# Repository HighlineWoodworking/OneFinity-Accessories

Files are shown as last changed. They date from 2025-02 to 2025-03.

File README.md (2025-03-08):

# OneFinity-Accessories
Accessories for a [OneFinity CNC Machine](https://www.onefinitycnc.com/).

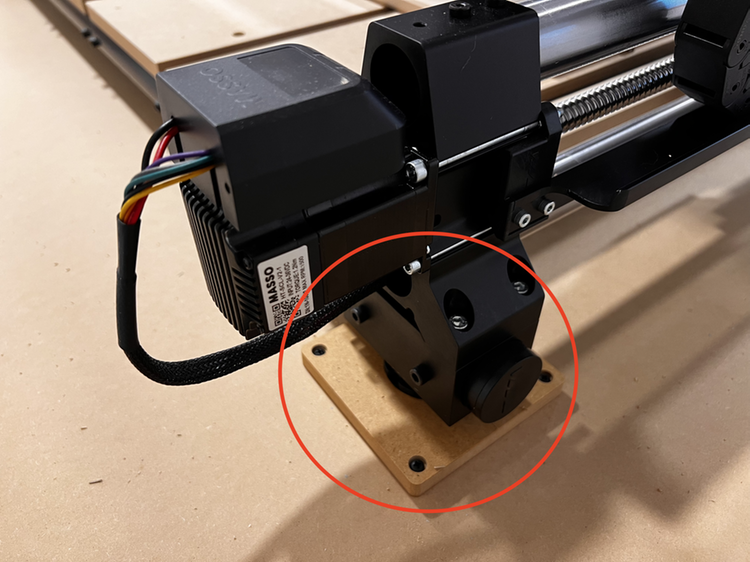
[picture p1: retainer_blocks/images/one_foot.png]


[Retainer Blocks](retainer_blocks/README.md)

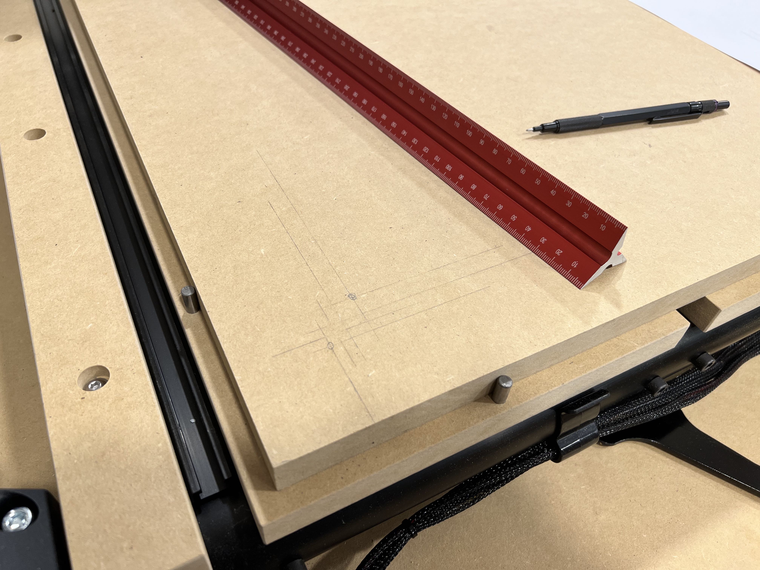
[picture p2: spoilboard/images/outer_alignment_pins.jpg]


[Spoilboard (work in progress)](spoilboard/README.md)

## Using

Projects and files are 100% free to use under [CC0](https://creativecommons.org/public-domain/cc0/).

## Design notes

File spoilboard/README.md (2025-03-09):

# Spoilboard

Spoilboard setup on a [OneFinity Journeyman Elite](https://www.onefinitycnc.com/product-page/elite-series-journeyman-48-x32-cut-area) with a QCW frame.  

Utilizes one or more sacrifical layers on top of the QCW slats.

## Advantages

* Multiple levels provide felxibility, minimize torque, and protect the QCW slats
* Alignment pins maintain a high-degree of repeatable accuracy
* Embedded hurricane nuts allow for secure, low-profile hold-downs
* Follows the "MFT Standard" 96mm grid spacing

## Disadvantages

* Not ideal where a maximum z-range is needed
* "MFT Standard" adds complexity, a simpler grid system would be better

## Steps

1. Flatten QCW boards
2. Machine [Outer Alignment Holes](outer_alignment_holes.md)
3. Setup lower spoilboard blank
4. [Add Fastening Holes](fastening_holes.md)

## Materials

* [1/4" Alignment Pins McMaster-Carr](https://www.mcmaster.com/catalog/131/3826/98381A542)

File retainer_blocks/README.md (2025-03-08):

# OneFinity QCW Retainer Blocks

Retainer blocks to secure the OneFinity Elite QCW to a table. The frame combined with the OneFinity is rock solid, but the blocks provide extra protection to keep the machine from "walking" across the table. Blocks are split in half allowing them to be installed once the machine is setup.

QCW Retainer Block on one Foot.

## Notes

* drawing units are mm
* 300 x 340mm blank
* 12.7mm (1/2 inch) MDF
* simple machining with 1/4 inch end mill
* (16) x #8 1 inch coarse pan head screws to secure blocks to a work surface
* [Amazon Link for Screws](https://www.amazon.com/gp/product/B01M63E8DR/ref=ppx_yo_dt_b_search_asin_title?ie=UTF8&psc=1)
* inset fastening holes 3mm

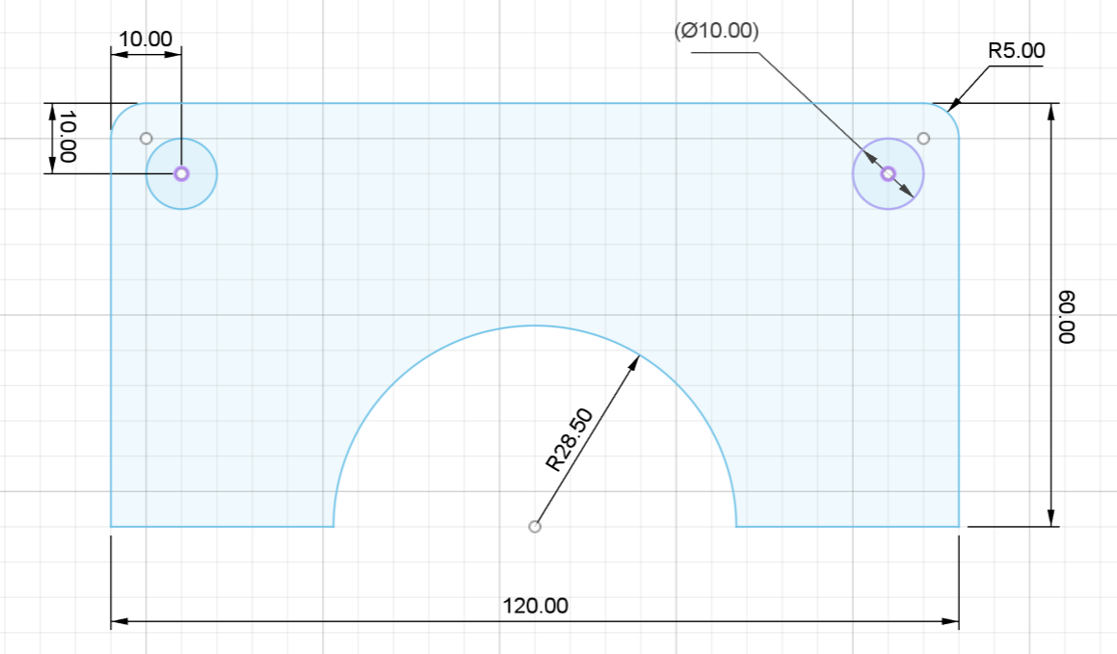
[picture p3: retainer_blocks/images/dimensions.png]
QCW Retainer Block dimensions.


## Files

* qcw_retainer_blocks_v01.art = [Carveco Maker](https://carveco.com/carveco-software-range/carveco-maker/) source file
* qcw_retainer_blocks_v01.dxf = [DXF](https://en.wikipedia.org/wiki/AutoCAD_DXF) source file 

## Versions

* v01 | 9-Feb-2025 | inital post

Finished pieces can also be purchased from the [Highline Woodworking Etsy Shop](https://www.etsy.com/shop/HighlineWoodworking)

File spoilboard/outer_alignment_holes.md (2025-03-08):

# Outer Alignment Holes

* Precisely aligns left and bottom edge of spoilboard on the QCW frame
* Peck holes 12.7mm deep (1/2 inch) using a 1/4 inch up-cut end mill, for example:
  * [Woodpeckers US2100U](https://www.woodpeck.com/ultra-shear-2-flute-quarter-inch-solid-carbide-spiral-bits.html)
* Holes are setup so board is positioned 10mm in from lower-left edge of left-most large QCW slat
* For 1/4 inch bit, hole center is 6.825mm from edges
* Holes spaced approximately in the middle of the QCW boards along X and equally along Y
* Alignment pins are more accurate and reliable than using a line and manually positioning the spoilboard
* Since the holes are CNC routed the spoilboard will be precisely aligned with the CNC X and Y axes

Outer alignment pins.
Spoilboard aligned with 1/4 inch alignment pins 10mm in from the lower-left corner of the leftmost wide QCW slat.

## Files

* outer_alignment_holes.art = [Carveco Maker](https://carveco.com/carveco-software-range/carveco-maker/) source file
* outer_alignment_holes.dxf = [DXF](https://en.wikipedia.org/wiki/AutoCAD_DXF) exported source file
* outer_alignment_holes.dwg = AutoCad drawing file created with [Siemens Solid Edge 2D](https://resources.sw.siemens.com/en-US/download-free-2d-cad-software/)

## Dimensions

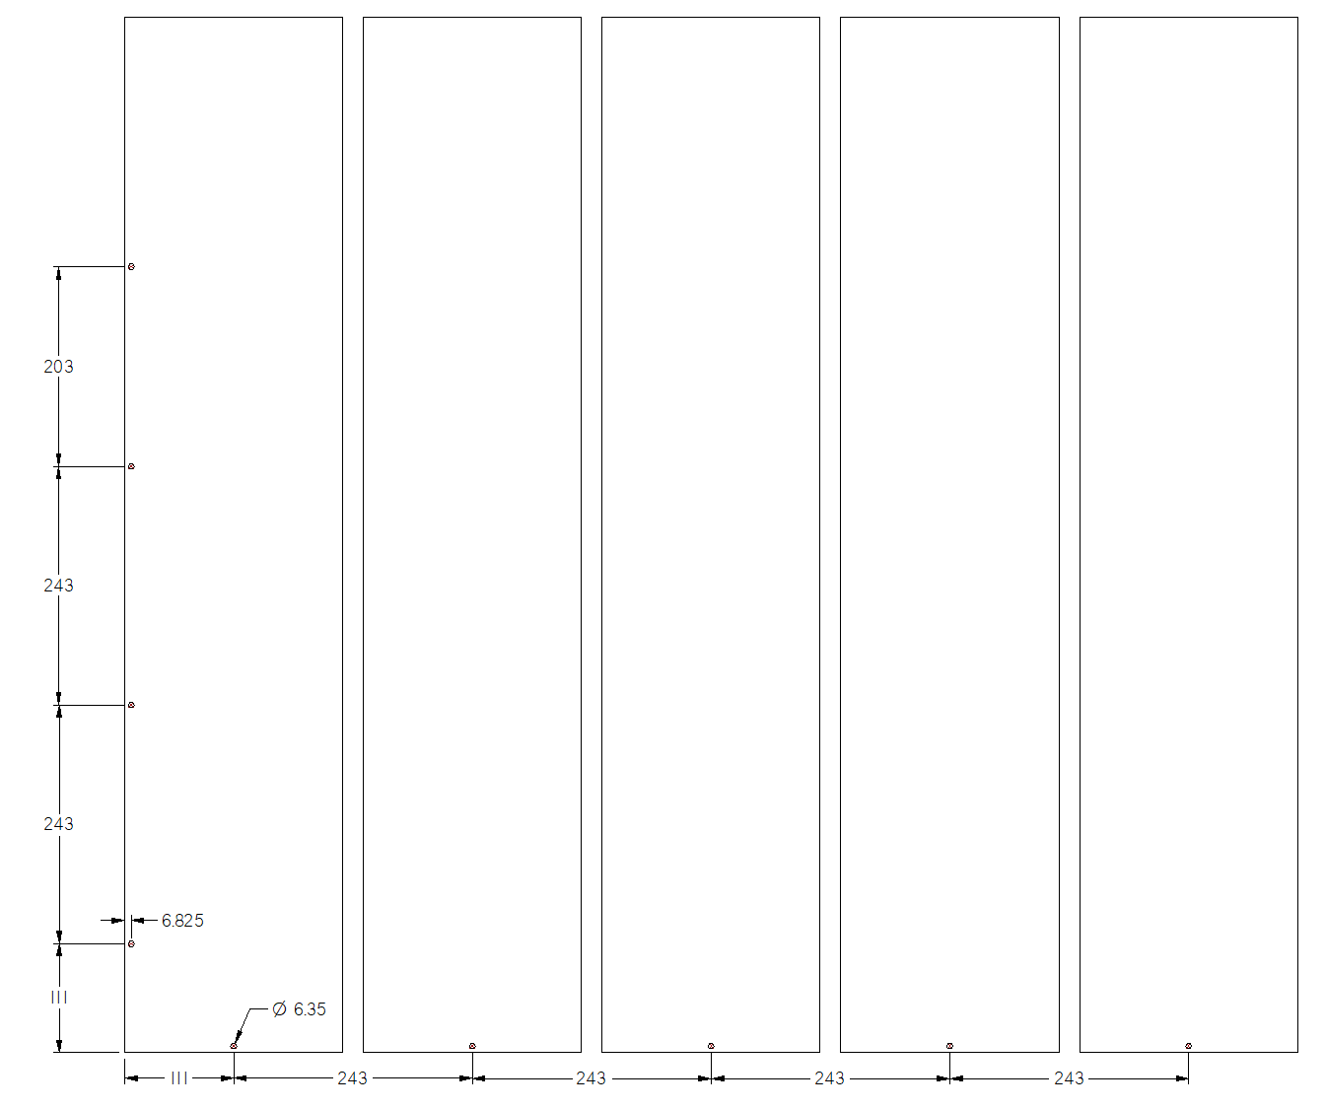
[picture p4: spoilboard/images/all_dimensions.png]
All dimensions.


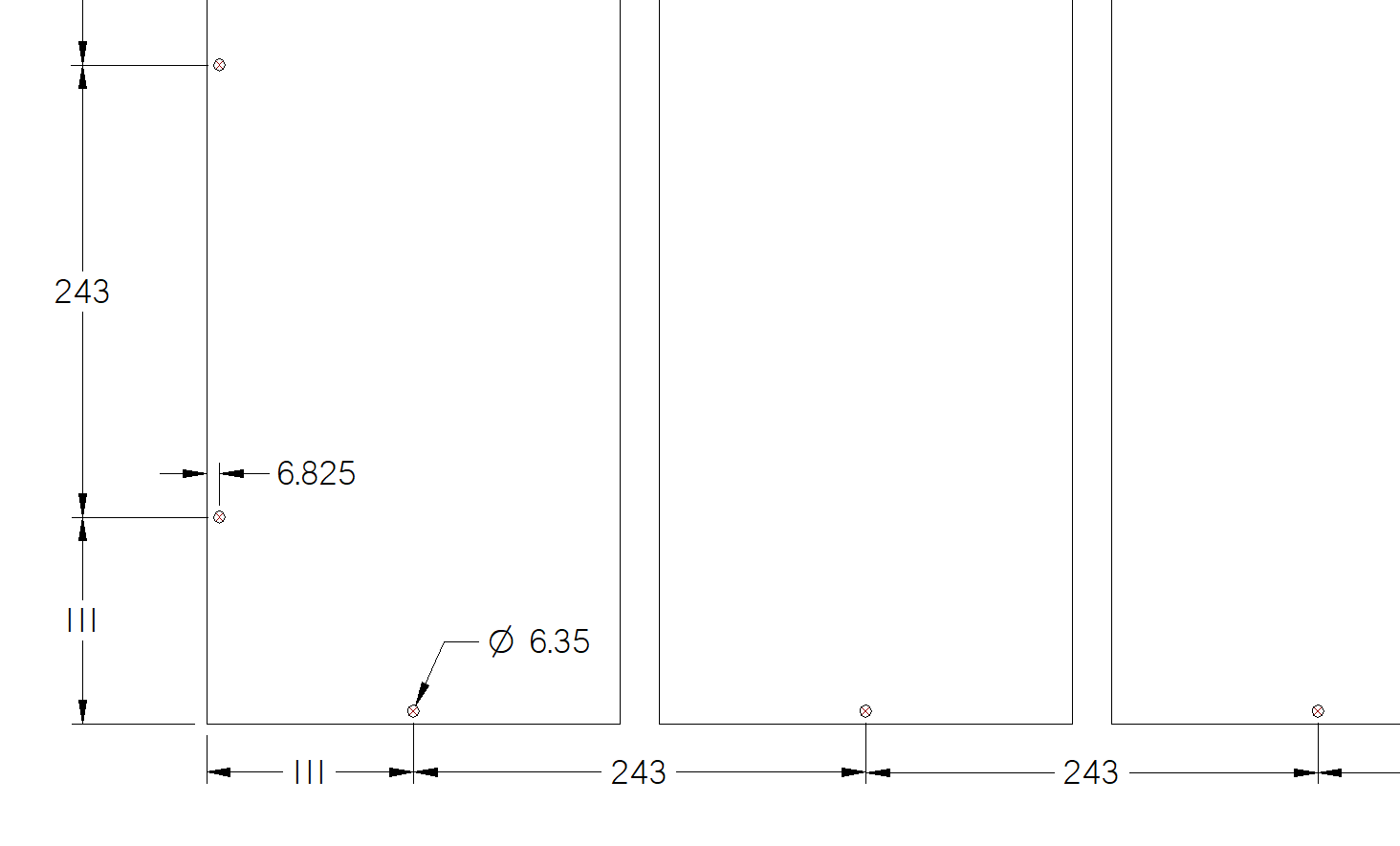
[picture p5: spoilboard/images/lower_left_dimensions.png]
Lower left dimensions.


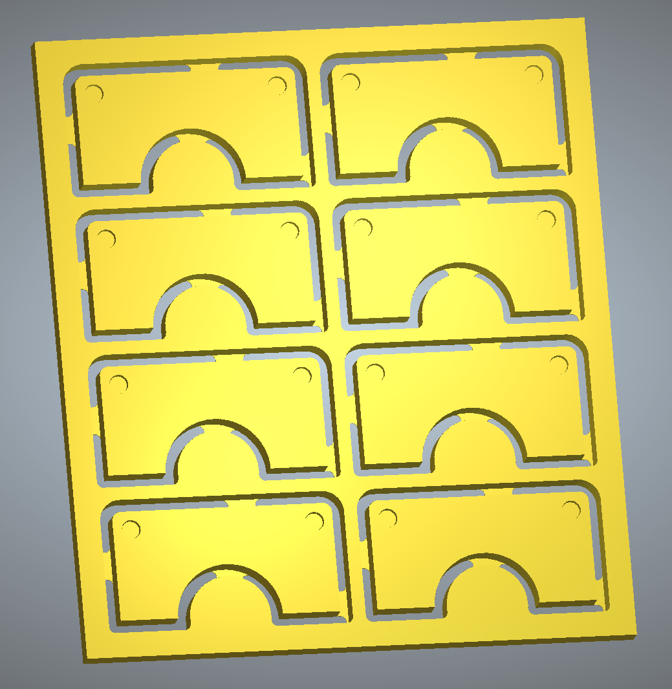
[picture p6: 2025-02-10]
retainer_blocks/images/3d_rendering.png

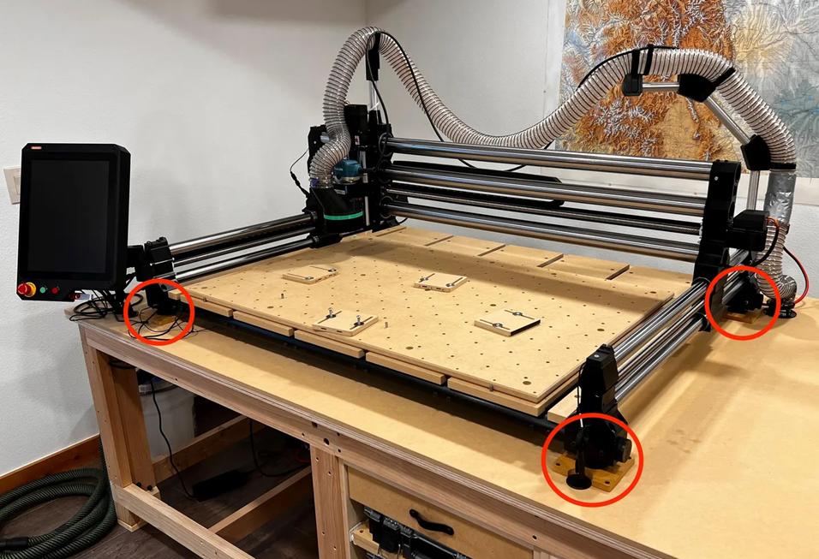
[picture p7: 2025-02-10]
retainer_blocks/images/three_feet.png

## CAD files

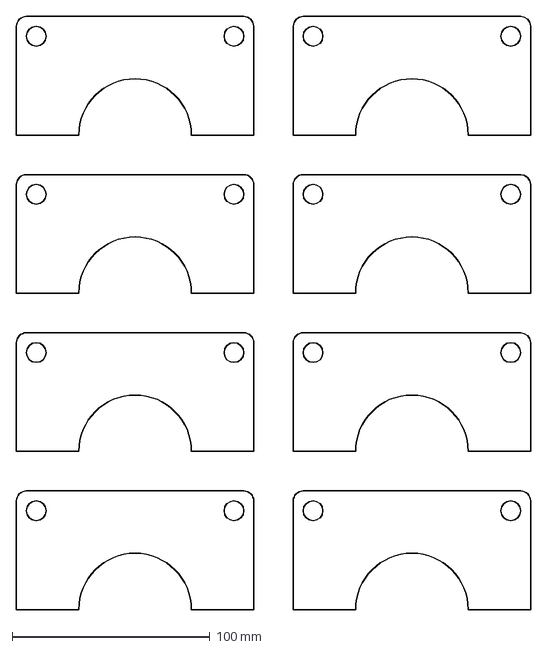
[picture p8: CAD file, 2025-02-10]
retainer_blocks/qcw_retainer_blocks_v01.dxf
260.0 x 300.0 mm

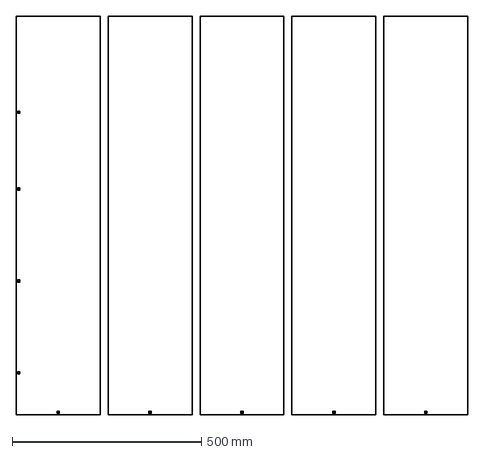
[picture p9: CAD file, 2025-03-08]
spoilboard/outer_alignment_holes.dxf
1194.0 x 1054.0 mm

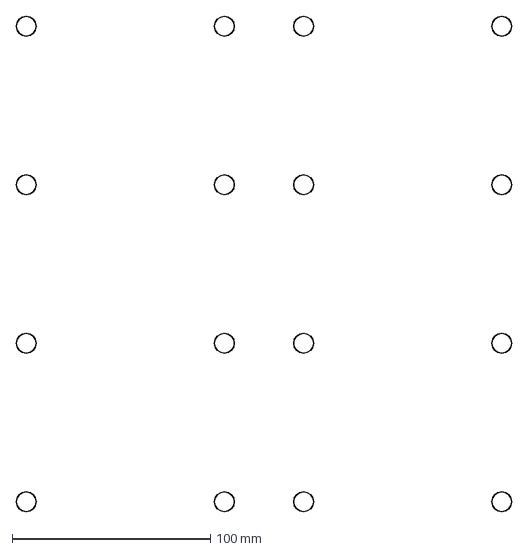
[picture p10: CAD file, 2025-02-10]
retainer_blocks/v01_fastening_insets.dxf
250.0 x 250.0 mm

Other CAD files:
spoilboard/outer_alignment_holes.dwg

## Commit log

2025-02-10 Added retainer blocks DXF files.
    [highline_woodworking_qcw_retainer_blocks_v01_fastening_insets.dxf, highline_woodworking_qcw_retainer_blocks_v01_outlines.dxf]
2025-02-10 Simplified DXF filenames.
    [v01_fastening_insets.dxf, v01_outlines.dxf]
2025-02-10 Added dimensions image and single DXF.
    [qcw_retainer_blocks_v01.dxf]
2025-02-10 Deleted separate DXFs.
    [v01_fastening_insets.dxf, v01_outlines.dxf]
2025-03-08 Outer alignment holes files and dimensions.
    [outer_alignment_holes.dwg, outer_alignment_holes.dxf]
